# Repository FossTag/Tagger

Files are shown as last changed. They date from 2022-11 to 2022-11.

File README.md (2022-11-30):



Repurpose your old nerf-or-similar toy guns that were destined for the trash heap.
Rip their guts out, and replace them with this Open Hardware, Arduino based PCB, an infrared LED, a trigger switch, and optionally some LEDs and/or speakers for feedback.

Print the PCB yourself at a commercial fabrication shop, or hack together your own using a bit of stripboard using the relatively straightforward schematics.

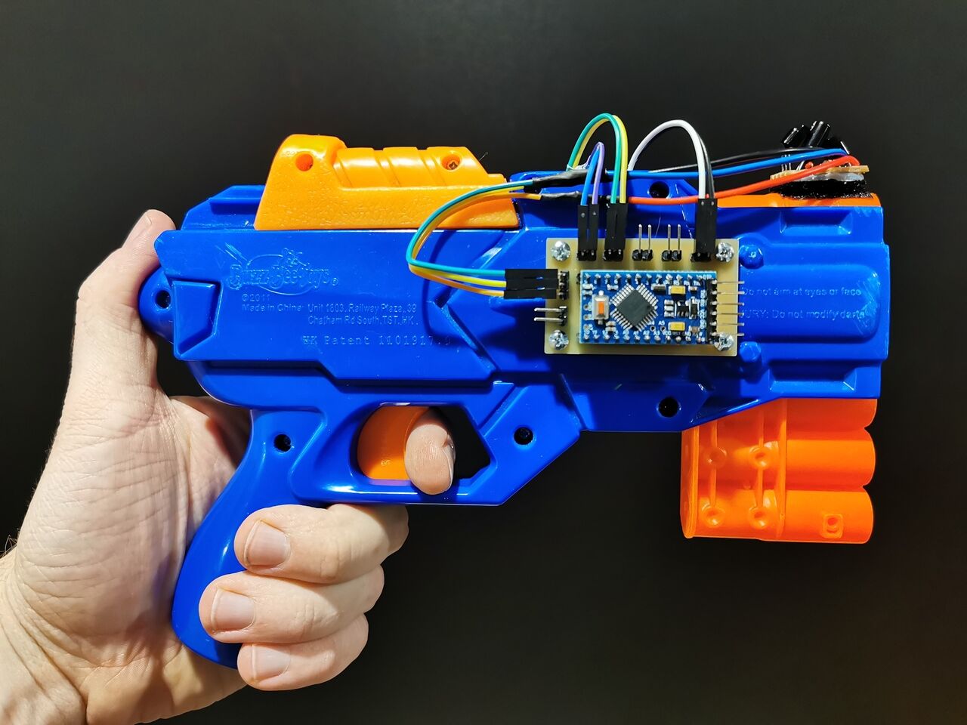
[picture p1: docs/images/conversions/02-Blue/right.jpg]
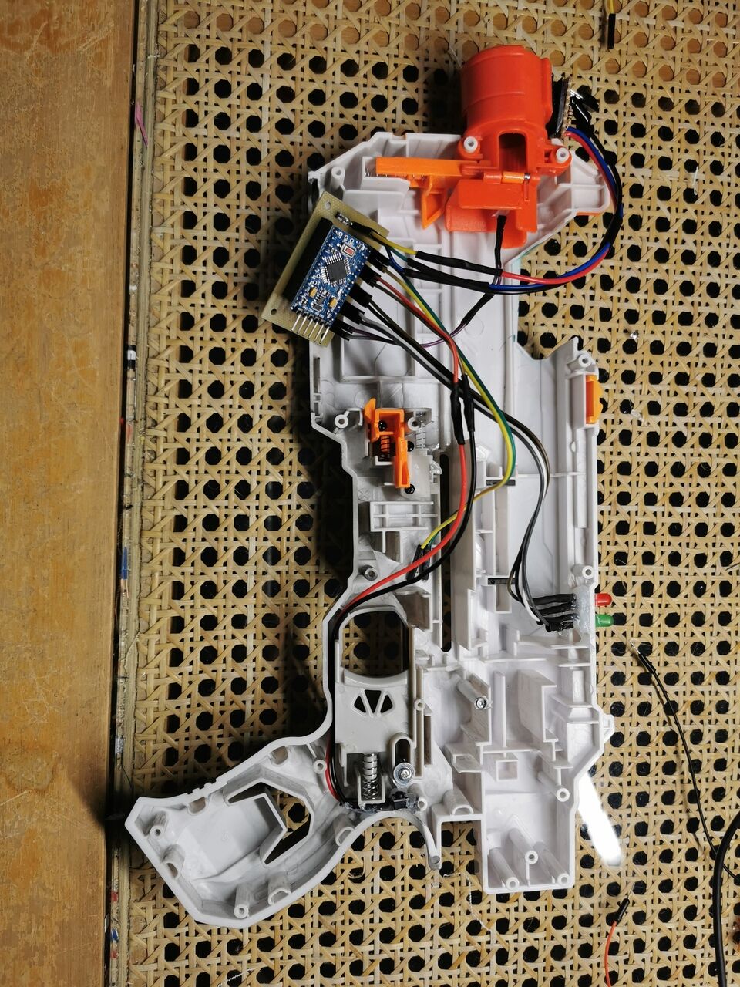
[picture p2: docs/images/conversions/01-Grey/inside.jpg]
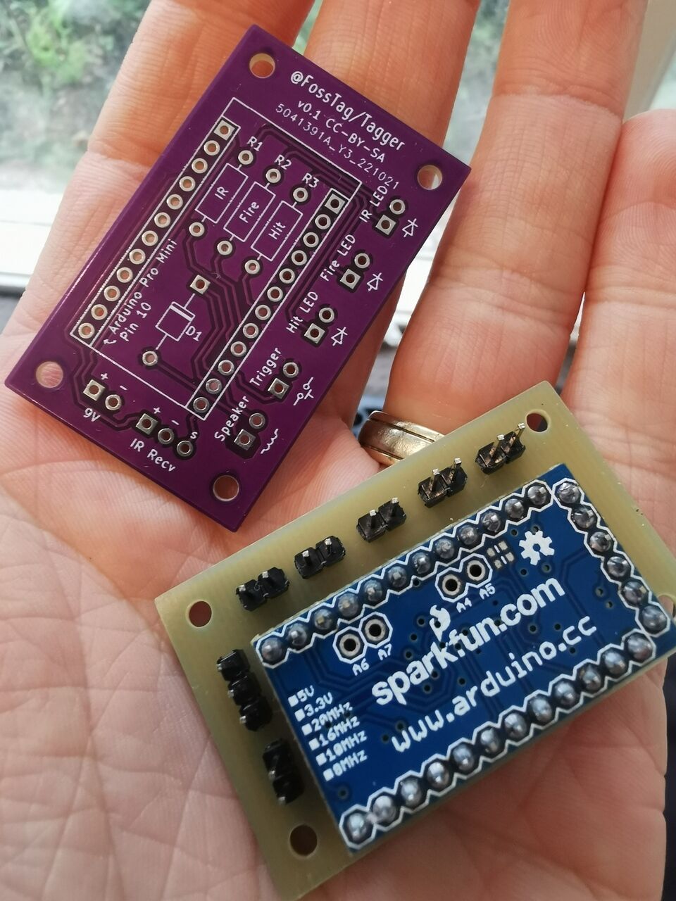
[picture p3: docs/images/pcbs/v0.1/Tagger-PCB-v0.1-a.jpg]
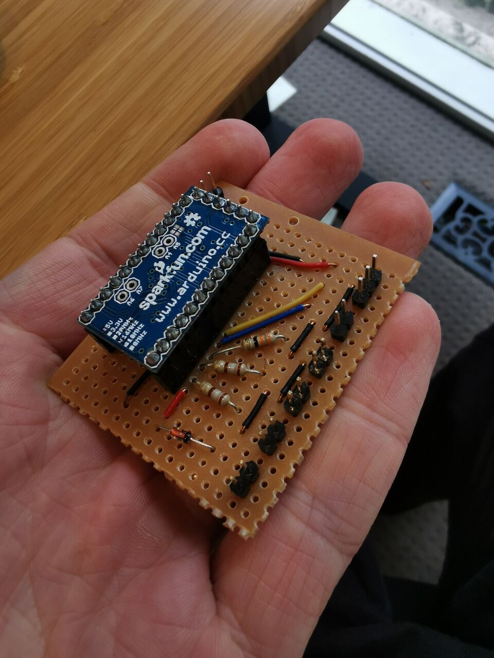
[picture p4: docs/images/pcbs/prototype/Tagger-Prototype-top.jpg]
   

## See also

* **[@FossTag](https://github.com/FossTag)** - for an overview of the broader project.
* **[@FossTag/TaggerFirmware](https://github.com/FossTag/TaggerFirmware)** - for the latest firmware for this PCB.

## PCB design

Currently, the PCB supports the following:
* Mounting an Arduino Pro Mini.
* Trigger button and IR LED for firing.
* RGB LED and speaker for audio/visual feedback.
* Battery input from a 9V or other appropriate battery.

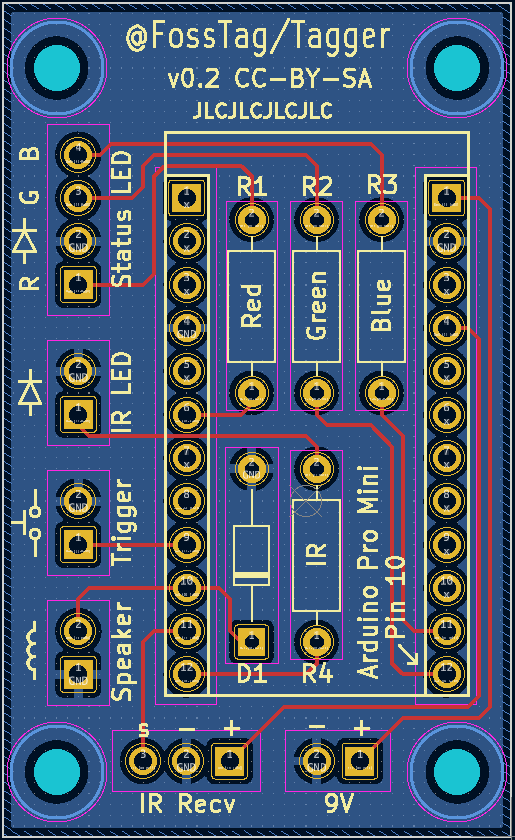
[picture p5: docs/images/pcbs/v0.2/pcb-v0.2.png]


For details of the latest and all past revisions, check out the [GitHub Releases](https://github.com/FossTag/Tagger/releases) page.
It will include a detailed description of each PCB revision, and also Kicad source files + some Gerber files for specific PCB manufacturers.

### Approx list of materials
* Old nerf gun (and some creativity)
* Arduino Pro Mini
    * 5V version if you wish to drive a piezo speaker for audio feedback
    * 3V otherwise
* 9V battery (or other power source that can connect to the Arduino Pro Mini raw voltage input pin)
* IR LED + resistor for firing
* Momentary switch for trigger
* Optional:
    * 2 x LEDs + resistors for visual feedback of firing and getting hit.
    * 1 x Piezo speaker for audio feedback of firing, getting hit, and dying.

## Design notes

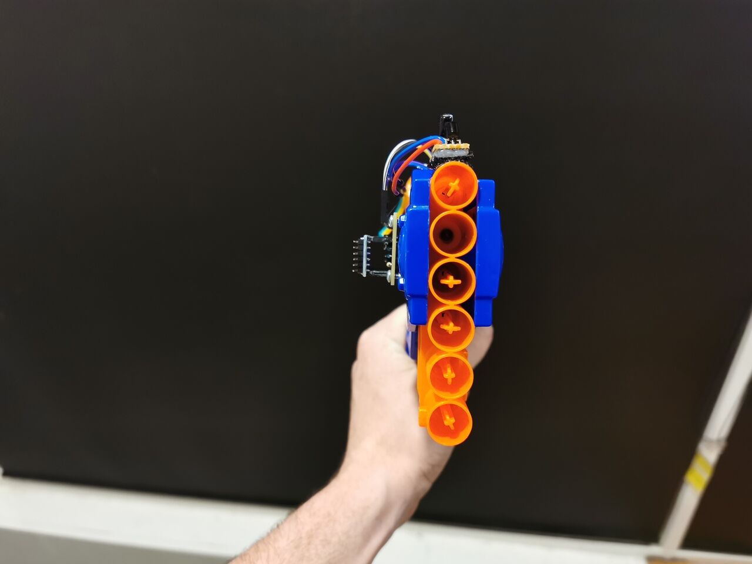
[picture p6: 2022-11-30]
docs/images/conversions/02-Blue/barrel.jpg

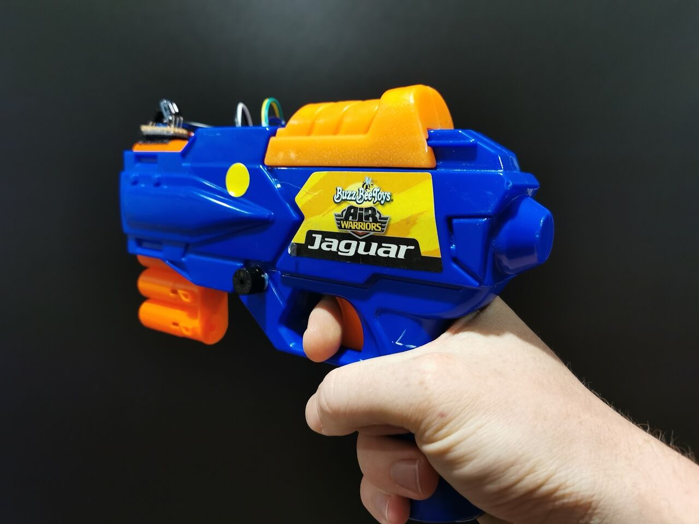
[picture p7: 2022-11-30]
docs/images/conversions/02-Blue/right-hand.jpg

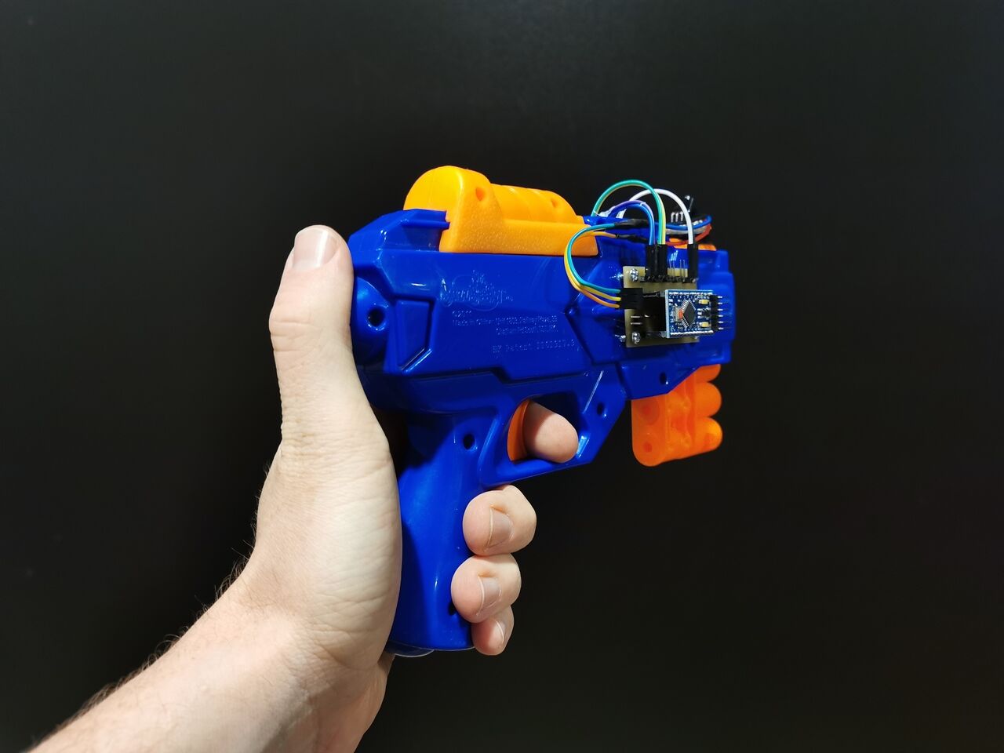
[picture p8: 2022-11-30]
docs/images/conversions/02-Blue/left-hand.jpg

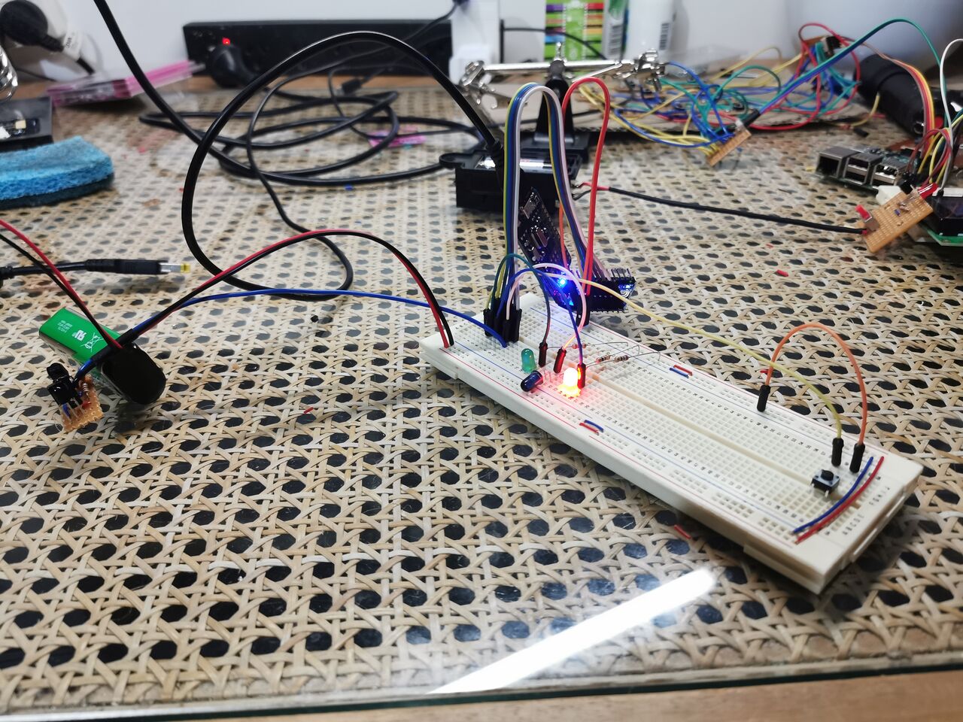
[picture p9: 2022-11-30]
docs/images/pcbs/breadboard/breadboard-tagger-a.jpg

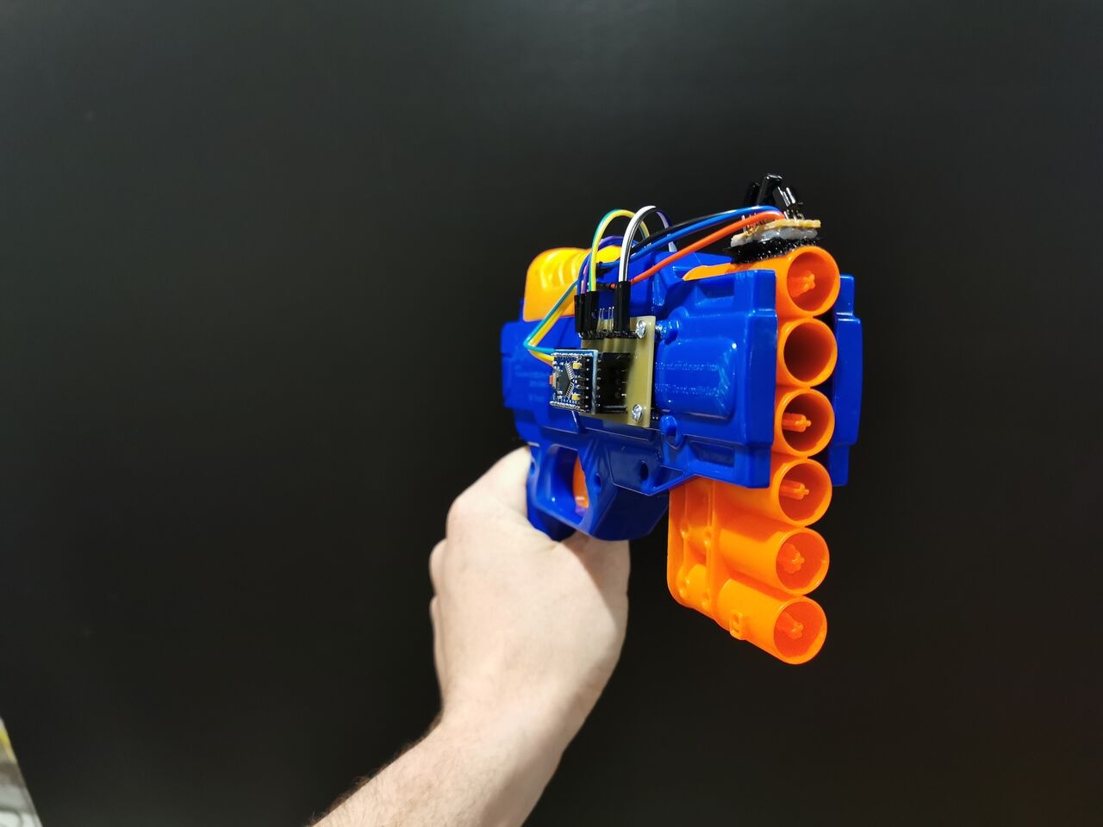
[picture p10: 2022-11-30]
docs/images/conversions/02-Blue/front.jpg

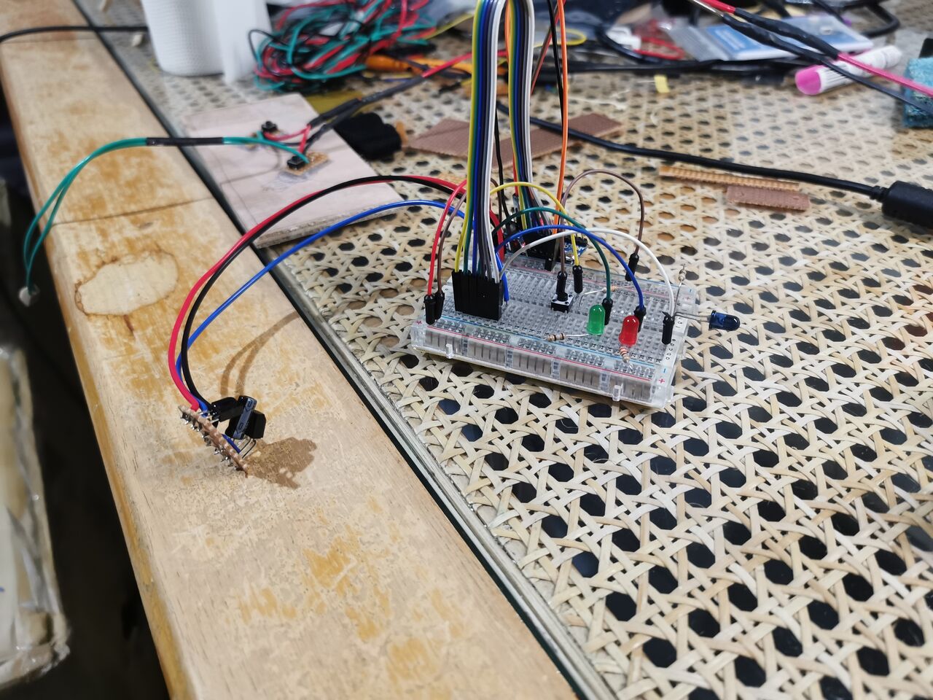
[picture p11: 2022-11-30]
docs/images/pcbs/breadboard/breadboard-tagger-b.jpg

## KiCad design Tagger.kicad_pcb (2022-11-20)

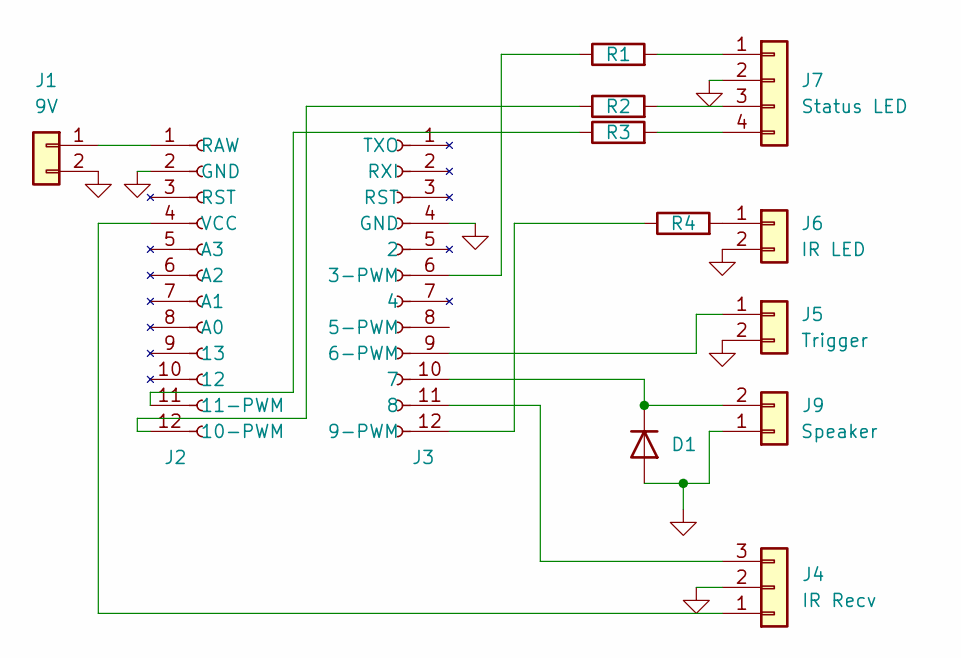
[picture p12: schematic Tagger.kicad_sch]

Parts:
D1: D; D_T-1_P10.16mm_Horizontal
J1: 9V; PinHeader_1x02_P2.54mm_Vertical
J2, J3: Conn_01x12_Female; PinSocket_1x12_P2.54mm_Vertical
J4: IR Recv; PinHeader_1x03_P2.54mm_Vertical
J5: Trigger; PinHeader_1x02_P2.54mm_Vertical
J6: IR LED; PinHeader_1x02_P2.54mm_Vertical
J7: Status LED; PinHeader_1x04_P2.54mm_Vertical
J9: Speaker; PinHeader_1x02_P2.54mm_Vertical
R1, R2, R3, R4: R; R_Axial_DIN0207_L6.3mm_D2.5mm_P10.16mm_Horizontal

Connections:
GND: D1.2 (A), J1.2, J2.2 (GND), J3.4 (GND), J4.2, J5.2, J6.2, J7.2, J9.1
unnamed: D1.1 (K), J3.10 (7), J9.2
unnamed: J1.1, J2.1 (RAW)
unnamed: J2.11 (11-PWM), R3.1
unnamed: J2.12 (10-PWM), R2.1
unnamed: J2.4 (VCC), J4.1
unnamed: J3.11 (8), J4.3
unnamed: J3.9 (6-PWM), J5.1
unnamed: J6.1, R4.2
unnamed: J3.6 (3-PWM), R1.1
unnamed: J7.1, R1.2
unnamed: J7.3, R2.2
unnamed: J7.4, R3.2
unnamed: J3.12 (9-PWM), R4.1

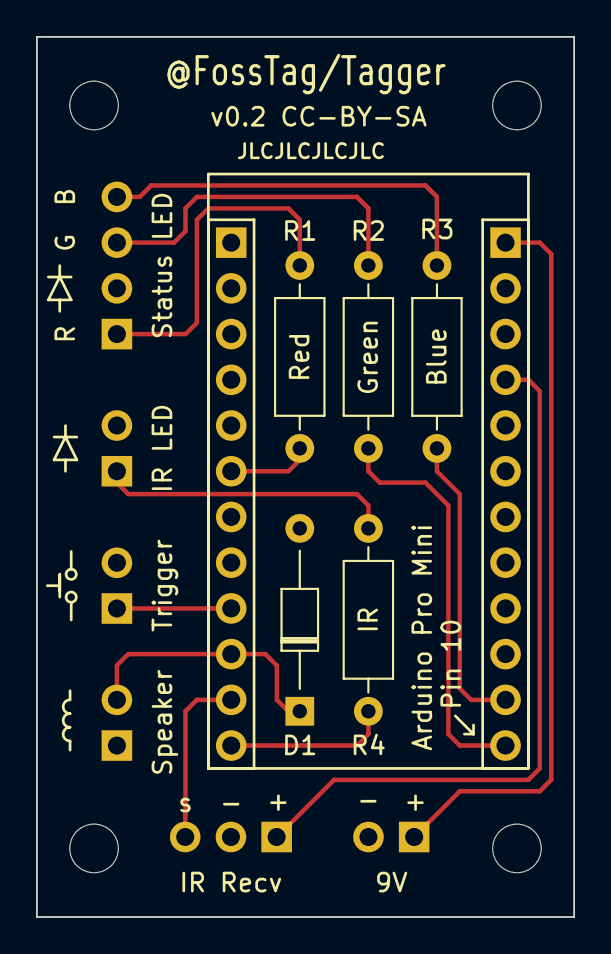
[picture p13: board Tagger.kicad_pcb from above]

Board: 2 copper layers, 29.8 x 48.9 mm, 13 parts (0 on the bottom side), 14 nets.

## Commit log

2022-11-16 First revision of Tagger board.
    Designed to mount an Arduino Pro Mini 5v/16MHz board via header pins,
    as well as IR LED, IR sensor, Hit + Status LEDs, and a trigger button.
    [Tagger.kicad_pcb, Tagger.kicad_sch]
2022-11-16 Working on revision 2.
    Diode is not strangely routed to ground any more, it is more sensible and direct.
    Ground plane moved to the back so that it can print as a 2 sided board with the
    silk screen on top (currently it is a one sided one with silk screen on the back
    accidentally).
    [Tagger.kicad_pcb]
2022-11-17 First moves towards v0.2 of the board.
    * Replace 2 x status LED's with a single RGB LED.
    * Dobule sided (ground plane on bottom).
    * Better routes for speaker diode.
    [Tagger.kicad_pcb, Tagger.kicad_sch]
2022-11-20 Flip mounted arduino so that it is correctly oriented when mounted on the front of the board.
    Involved moving all other headers mounts to the other side of the
    board so that it was easier to route. Also ensured we correctly
    use PWM pins for the RGB LED.
    [Tagger.kicad_pcb, Tagger.kicad_sch]
2022-11-20 Output gerber files to local directory.
    However, they are excluded from git right now, as we will eventually
    publish them as github releases.
    [Tagger.kicad_pcb]

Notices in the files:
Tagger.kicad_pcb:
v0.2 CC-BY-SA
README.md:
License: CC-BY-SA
